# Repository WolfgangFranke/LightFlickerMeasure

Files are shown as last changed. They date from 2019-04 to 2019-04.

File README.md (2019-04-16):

# Light Flicker Measure
## Measures flickering lights, like PWM driven LED-systems, using Arduino.

An old Light Bulb sends 80% constant light and a 20% sine waveform as 100 Hz noise ontop, so no flicker is recognized.

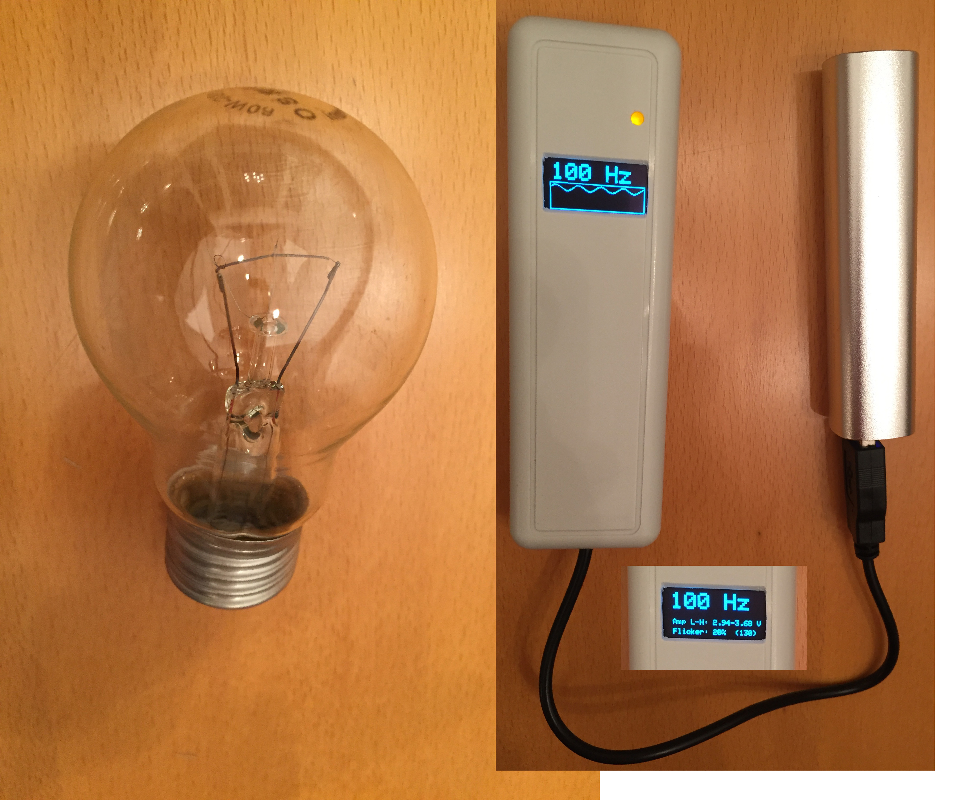
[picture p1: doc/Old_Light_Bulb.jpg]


This LED Streetlamp sends a permanent PWM of 264 Hz frequency instead of a steady light! Going for a walk at night, this lamp is really annoying.

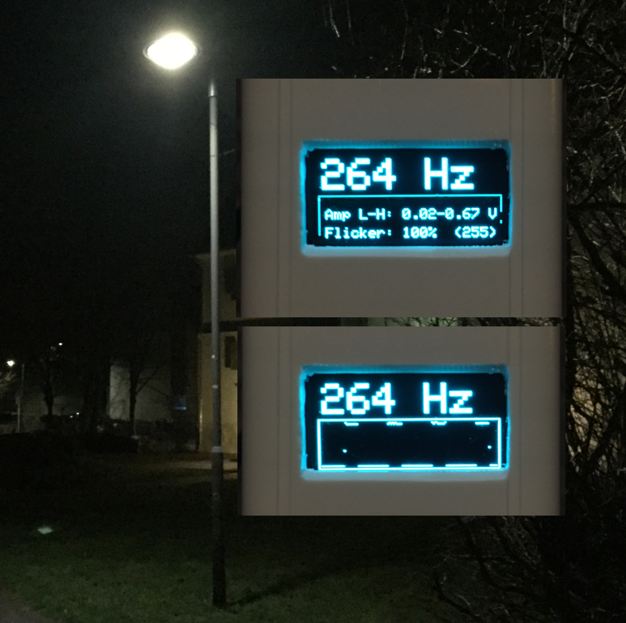
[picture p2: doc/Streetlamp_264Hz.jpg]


Philips Hue Being ceiling light and also the Philips Hue Light Strip+, as well as my Philips Hue RGB light bulbs, run at 1 kHz PWM. That still flickers irritatingly in your eyes when looking around in your appartment. I'm surprised seeing that the Hue Being let's overshoot the light at the begin of a PWM=high, but it may be seen due to the two LEDs providing the CCT.

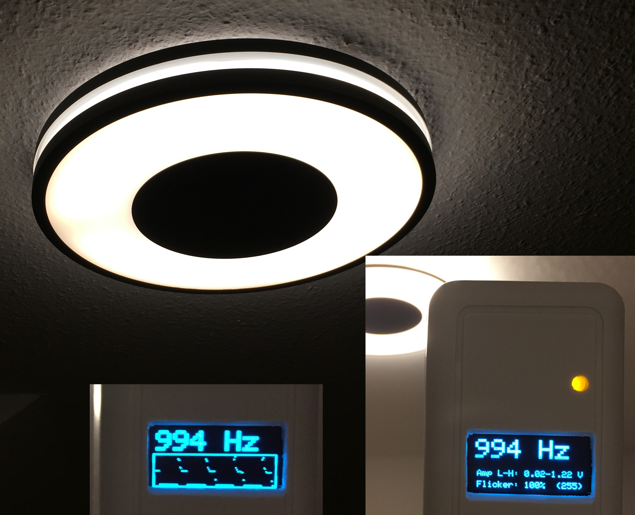
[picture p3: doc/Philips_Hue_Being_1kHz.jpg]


Talking about LED strips, the Paulmann SimpLED-Strip Set (789.56) dims in the PWM frequency range of 2,5 to 4 kHz. Covered by an opaque plastic housing, this could be considered it as less to no flicker. But if you install the strip in direkt sight, a strong flicker will be recognized when moving head or eyes.

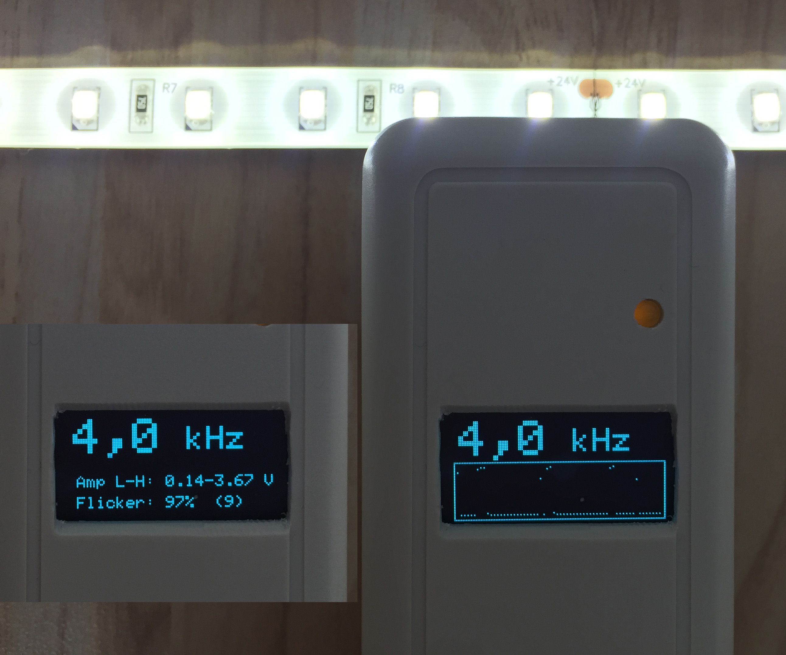
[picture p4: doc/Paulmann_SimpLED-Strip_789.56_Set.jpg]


Totally smooth light sent by a Philips Filament Bulb (not dimmable), I really enjoy it.

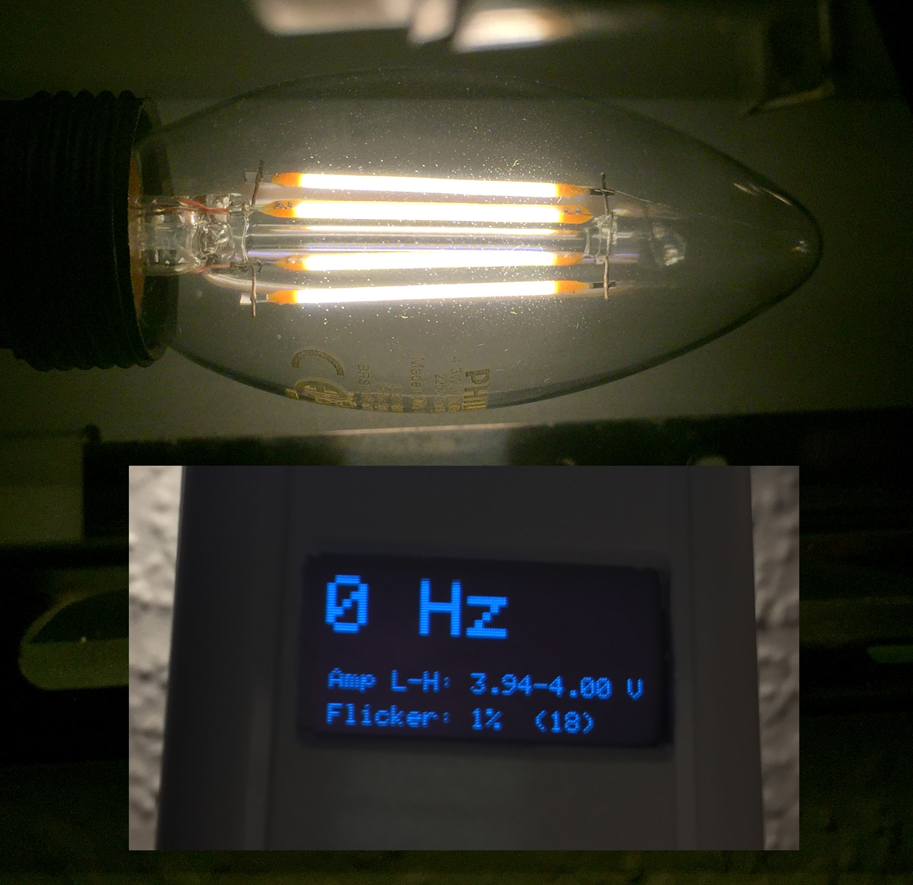
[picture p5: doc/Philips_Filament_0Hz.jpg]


And how about an old-fashioned Neon Lamp, where we all know it does not give a good light? Yep, it does not give a good light!

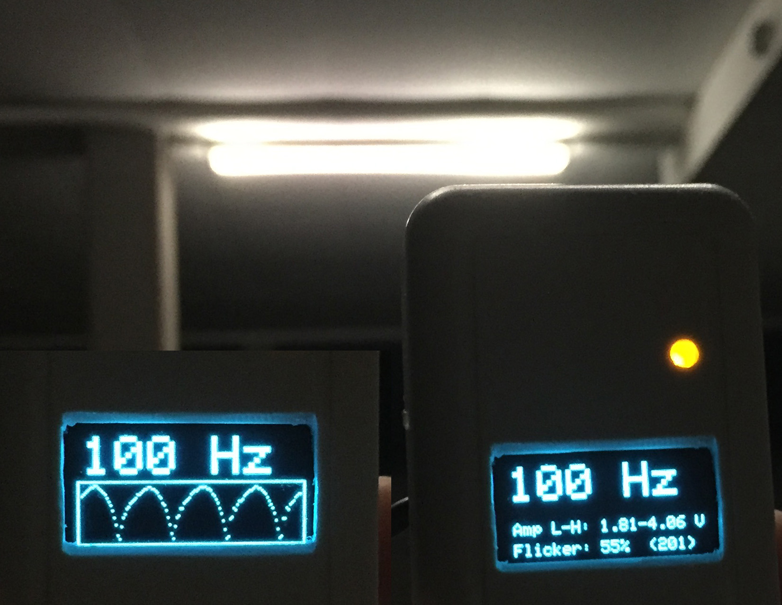
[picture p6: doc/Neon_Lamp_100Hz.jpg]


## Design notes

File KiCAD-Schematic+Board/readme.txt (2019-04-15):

This folder contains the schematic and board layout in KiCAD format.

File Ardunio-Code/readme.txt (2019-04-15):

This folder contains the Arduino scetch.

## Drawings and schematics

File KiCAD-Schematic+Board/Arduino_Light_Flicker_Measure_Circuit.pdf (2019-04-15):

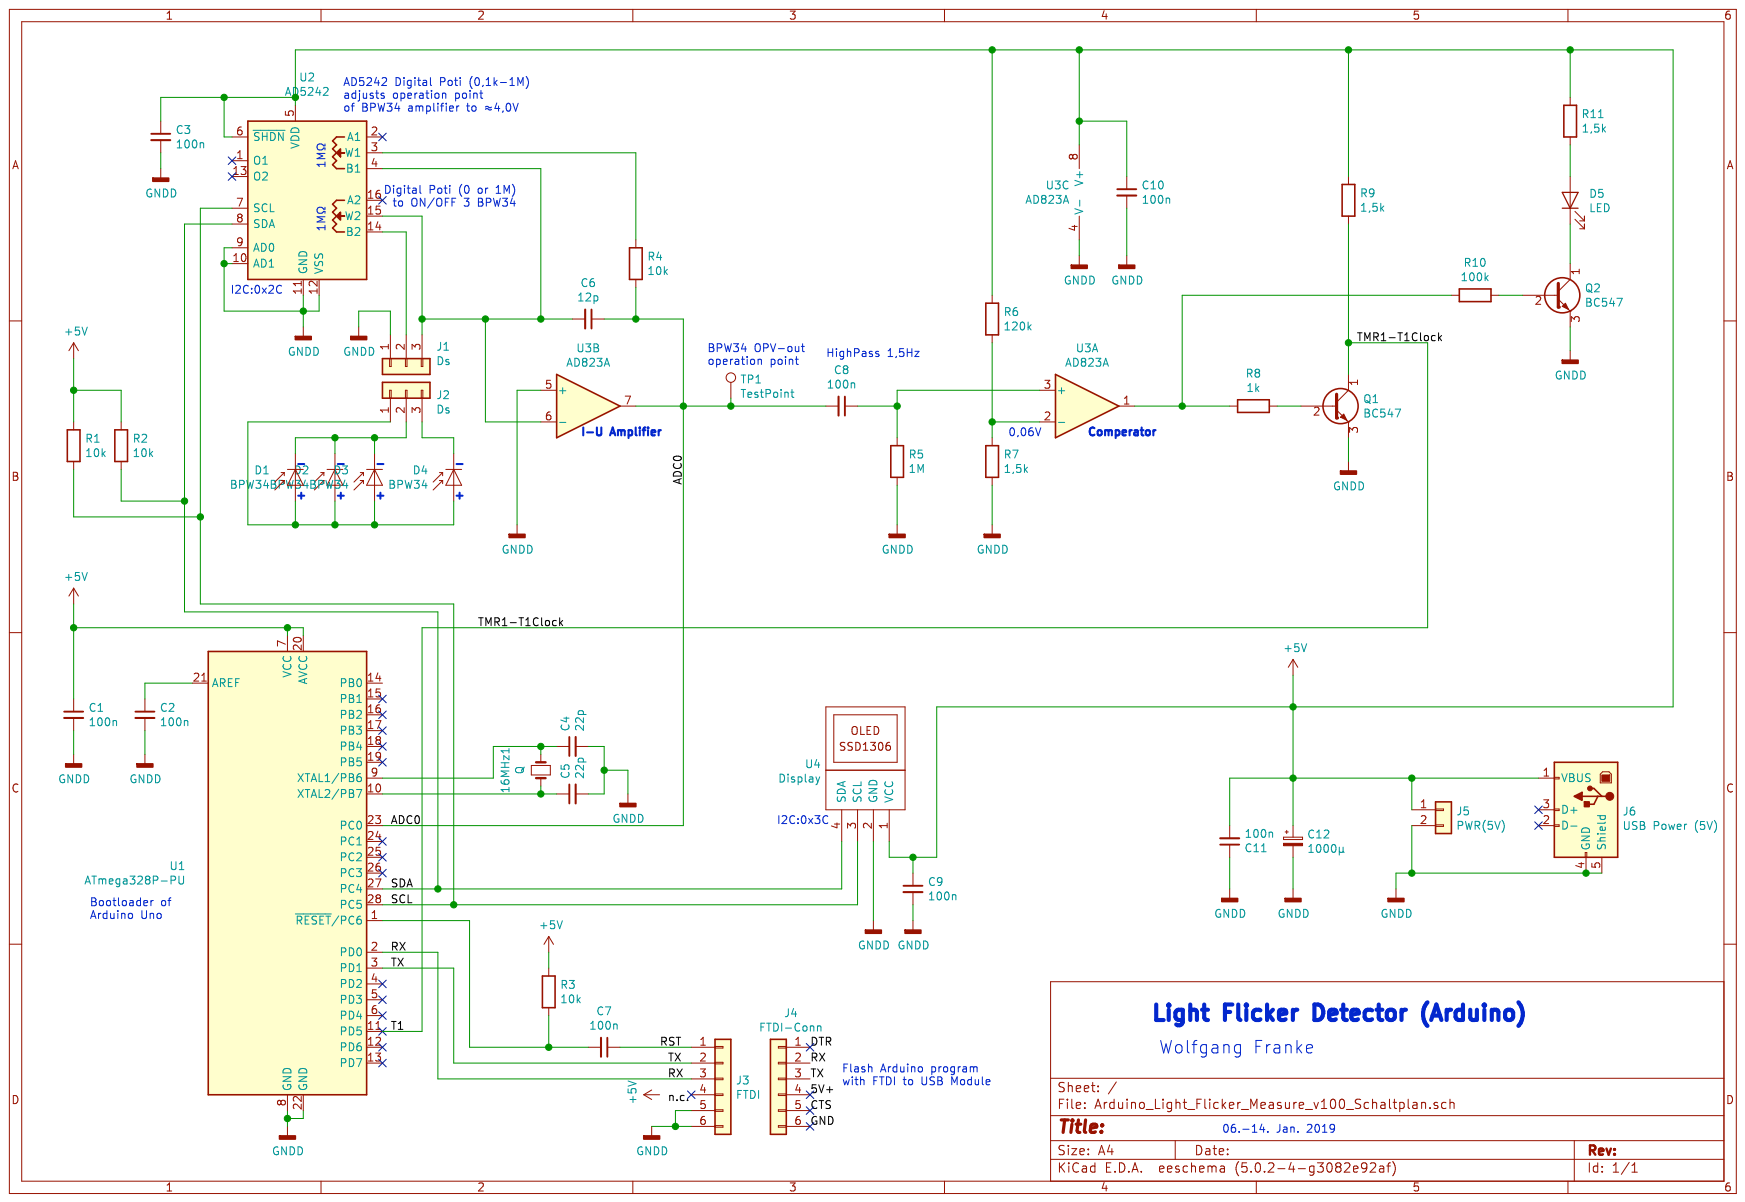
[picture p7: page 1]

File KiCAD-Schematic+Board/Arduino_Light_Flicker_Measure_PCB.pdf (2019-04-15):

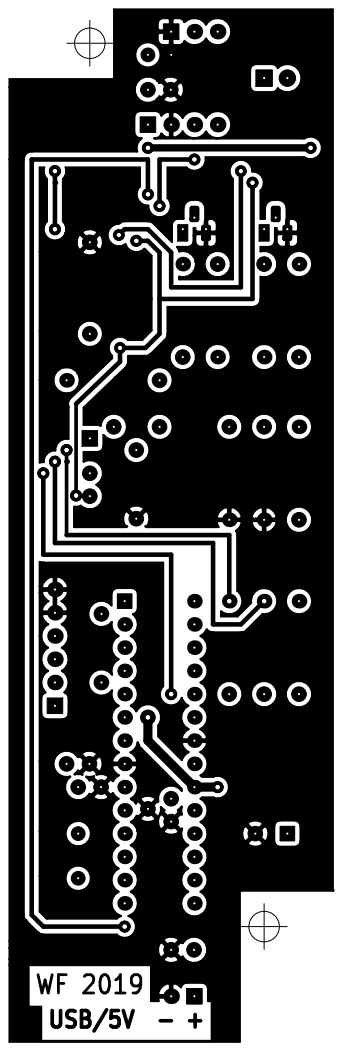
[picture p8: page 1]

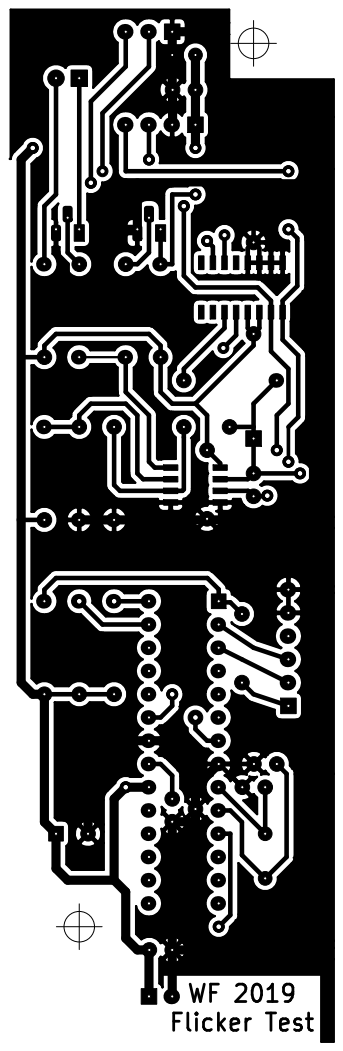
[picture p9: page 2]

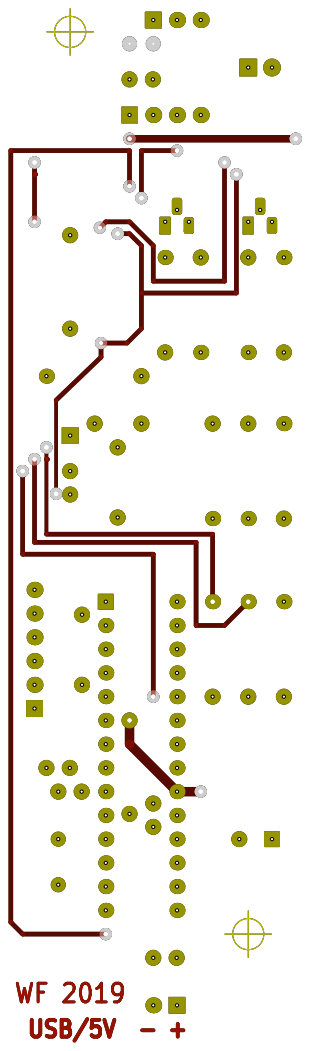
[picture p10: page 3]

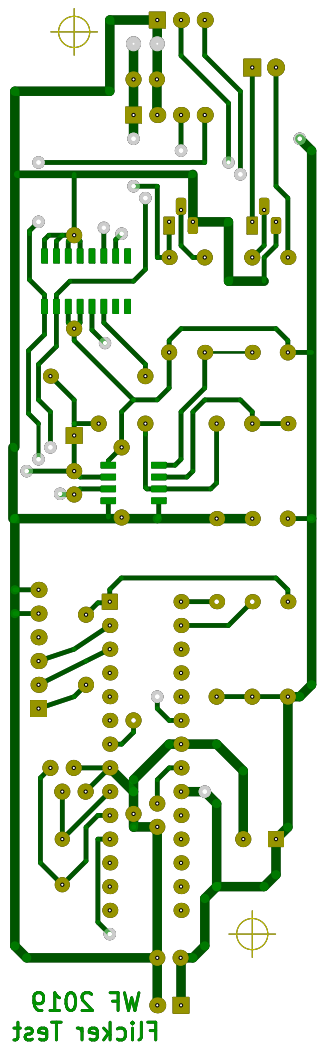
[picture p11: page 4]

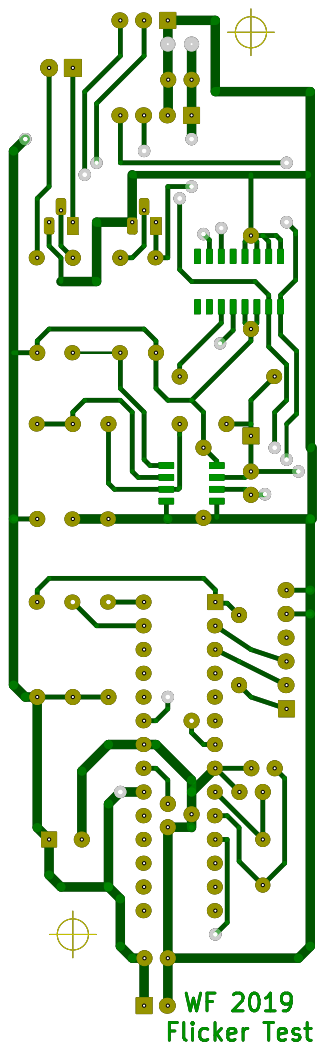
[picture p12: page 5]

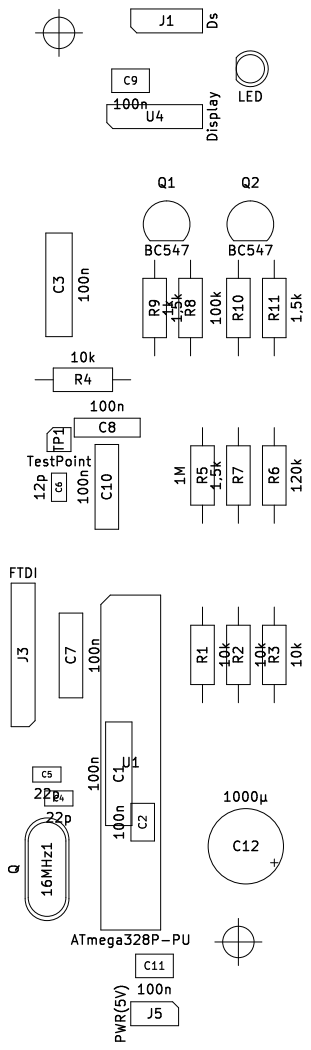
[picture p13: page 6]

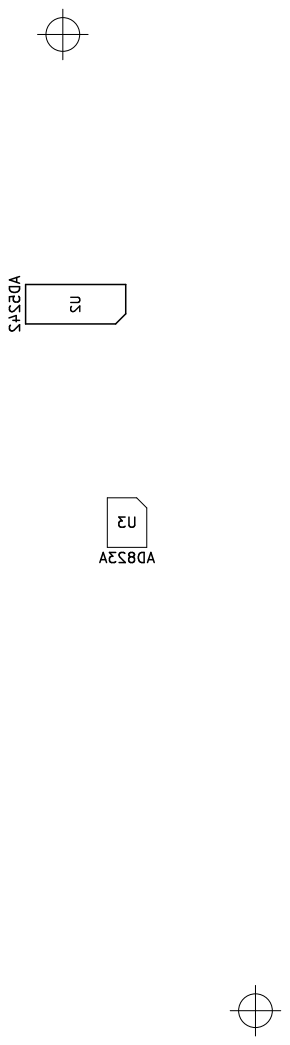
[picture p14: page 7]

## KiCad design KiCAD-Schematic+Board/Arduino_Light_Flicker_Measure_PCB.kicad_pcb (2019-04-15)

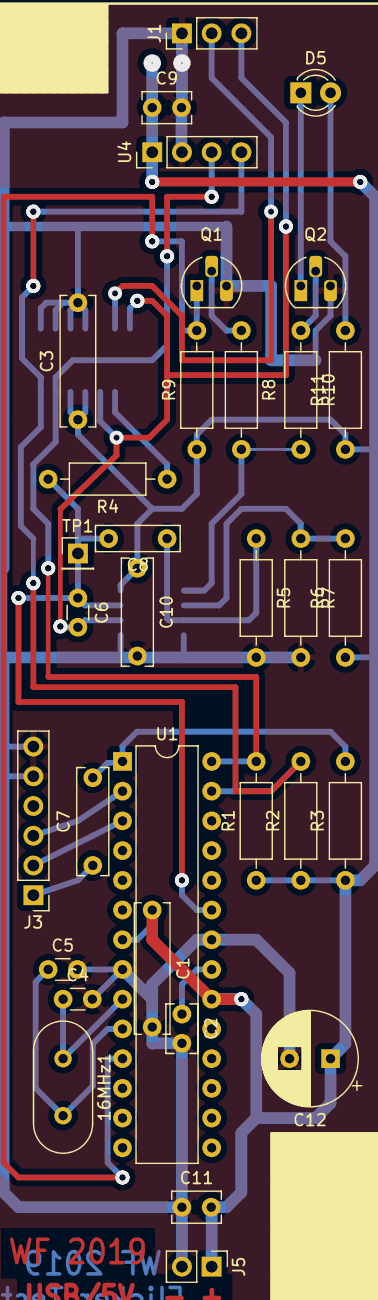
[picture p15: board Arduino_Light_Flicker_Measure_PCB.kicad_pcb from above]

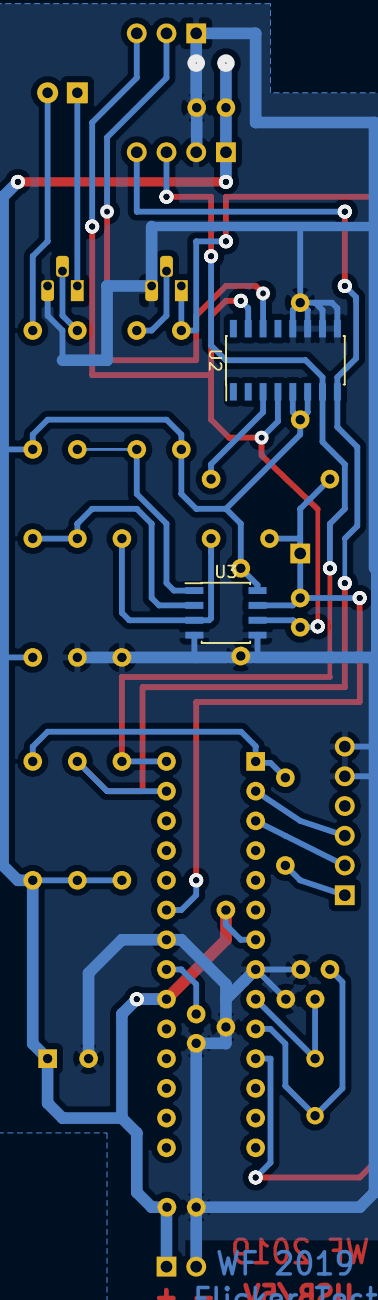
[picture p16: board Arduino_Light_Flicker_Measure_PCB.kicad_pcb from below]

Board: 2 copper layers, 35 parts (2 on the bottom side), 23 nets.

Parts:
16MHz1: Q; Crystal_HC49-U_Vertical
C1, C3: 100n; C_Rect_L11.0mm_W2.8mm_P10.00mm_MKT
C2, C9, C11: 100n; C_Rect_L4.0mm_W2.5mm_P2.50mm
C4, C5: 22p; C_Disc_D3.0mm_W1.6mm_P2.50mm
C6: 12p; C_Disc_D3.0mm_W1.6mm_P2.50mm
C7, C10: 100n; C_Rect_L9.0mm_W2.5mm_P7.50mm_MKT
C8: 100n; C_Rect_L7.0mm_W2.0mm_P5.00mm
C12: 1000µ; CP_Radial_D8.0mm_P3.50mm
D5: LED; LED_D3.0mm
J1: Ds; PinHeader_1x03_P2.54mm_Vertical
J3: FTDI; PinHeader_1x06_P2.54mm_Vertical
J5: PWR(5V); PinHeader_1x02_P2.54mm_Vertical
Q1, Q2: BC547; TO-92_HandSolder
R1, R2, R3, R4: 10k; R_Axial_DIN0207_L6.3mm_D2.5mm_P10.16mm_Horizontal
R5: 1M; R_Axial_DIN0207_L6.3mm_D2.5mm_P10.16mm_Horizontal
R6: 120k; R_Axial_DIN0207_L6.3mm_D2.5mm_P10.16mm_Horizontal
R7, R9, R11: 1,5k; R_Axial_DIN0207_L6.3mm_D2.5mm_P10.16mm_Horizontal
R8: 1k; R_Axial_DIN0207_L6.3mm_D2.5mm_P10.16mm_Horizontal
R10: 100k; R_Axial_DIN0207_L6.3mm_D2.5mm_P10.16mm_Horizontal
TP1: TestPoint; PinHeader_1x01_P2.54mm_Vertical
U1: ATmega328P-PU; DIP-28_W7.62mm
U2: AD5242; SOIC-16_3.9x9.9mm_P1.27mm
U3: AD823A; SOIC-8_3.9x4.9mm_P1.27mm
U4: Display; PinHeader_1x04_P2.54mm_Vertical

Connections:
+5V: C1.1, C3.1, C9.1, C10.1, C11.2, C12.1, J5.1, R1.1, R2.1, R3.1, R6.1, R9.1, R11.1, U1.7, U1.20, U2.5, U2.6, U3.8, U4.1
/ADC0: C6.1, C8.2, R4.2, TP1.1, U1.23, U3.7
/RST: C7.1, J3.1
/RX: J3.3, U1.2
/SCL: R1.2, U1.28, U2.7, U4.3
/SDA: R2.2, U1.27, U2.8, U4.4
/TMR1-T1Clock: Q1.1, R9.2, U1.11
/TX: J3.2, U1.3
GNDD: C1.2, C2.2, C3.2, C4.2, C5.2, C9.2, C10.2, C11.1, C12.2, J1.1, J3.5, J3.6, J5.2, Q1.3, Q2.3, R5.2, R7.2, U1.8, U1.22, U2.9, U2.10, U2.11, U2.12, U3.4, U3.5, U4.2
unnamed: 16MHz1.1, C4.1, U1.9
unnamed: 16MHz1.2, C5.1, U1.10
unnamed: C2.1, U1.21
unnamed: C6.2, J1.3, U2.4, U2.15, U3.6
unnamed: C7.2, R3.2, U1.1
unnamed: C8.1, R5.1, U3.3
unnamed: D5.1, Q2.1
unnamed: D5.2, R11.2
unnamed: J1.2, U2.14
unnamed: Q1.2, R8.1
unnamed: Q2.2, R10.1
unnamed: R4.1, U2.3
unnamed: R6.2, R7.1, U3.2
unnamed: R8.2, R10.2, U3.1

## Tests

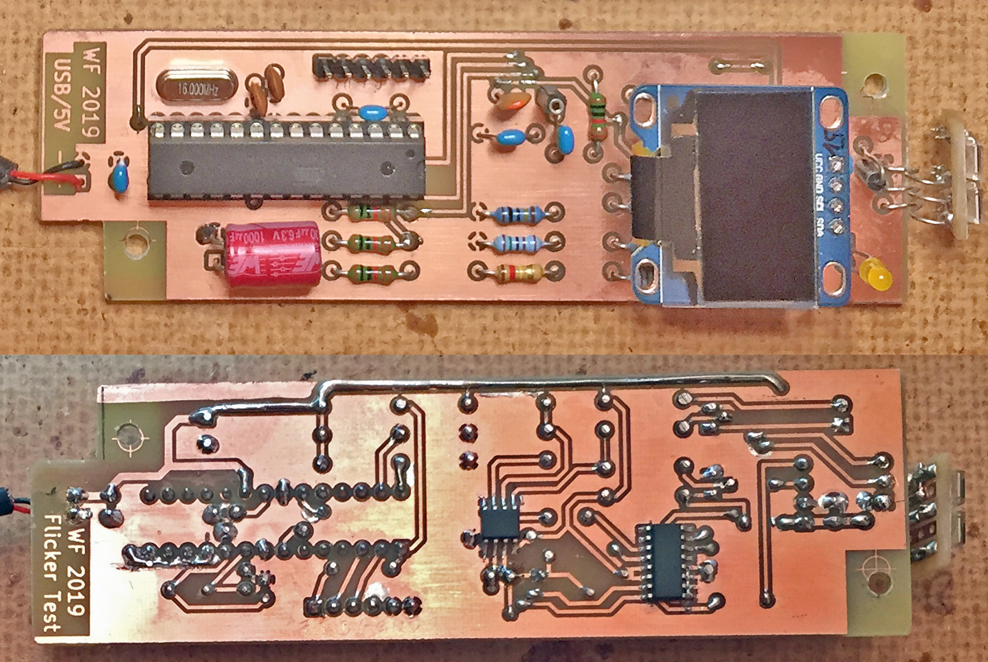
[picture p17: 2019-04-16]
KiCAD-Schematic+Board/Arduino_Light_Flicker_Measure_WF2019.jpg

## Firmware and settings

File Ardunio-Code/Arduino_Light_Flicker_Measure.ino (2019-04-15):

float SW_version = 1.01;
/*
' ######################################################################
' ###
' ###       *** Light Flicker Measure with Arduino (10Hz to 200KHz) ***
' ###       ----------------------------------------------------------
' ###       *Wolfgang Franke*
' ###       Projekt: 02.Jan.2019 - 26.Feb.2019
' ###       Software-Version 1.01    (used IDE: Arduino v1.8.8)
' ###       ----------------------------------------------------------
' ###       Hardware Setup:
' ###       - Analog:   
' ###           + BPW34 Photo Diodes (as fast Light Sensor to receive Light Frequency Pulses)
' ###           + AD823A dual OPV (to I-U convert and amplify light sensor pulses from BPW34) (TLC272 pin-compatible but much faster) 
' ###       - Digital:  
' ###           + ATMega328P with Arduino-Uno Bootloader and FDTI interface (5V, 16 MHz, 32MB Flash)
' ###             + Timer1-Counter clocked by TMR1 T1-externClock/PD5=D5 for counting Light Frequency Pulses
' ###             + ADC0 to measure OPV operation-point voltage (AD823A) and to sample waveform if flicker <10kHz
' ###           + OLED 128x64 (I2C Address: 0x3C)
' ###           + digital Poti AD5242-1M (I2C Address: 0xC2) to control OPV AD823A operation-point and turn ON/OFF 3 of the 4 BPW34 (to allow measure bright light)
' ###
' ###       Function of Light Frequency Measure Loop:
' ###       (1) adjust operating point of OPV (by BPW34 and in amplifier) to match out-signal to Comperator-Input before every Pulse Count of Ardunio CTC
' ###             Pulse high volt target: 4.0V (OPV_PulseHigh_Volt_target) as target operation point, for good signal-to-noise/sunlight ratio
' ###               light is too bright:  Pulse min voltage > 4.4V (OPV_PulseLow_Volt_saturate)
' ###               light is too dark:    Pulse max voltage < 0,1V (OPV_PulseHigh_Volt_weak)
' ###               not used: faint light flicker:  Difference of Pulse max-min voltage < 0,3V (OPV_Pulse_Volt_LH_weak)
' ###       (2) count Pulses (light flicker) on Timer1 T1-externClock-Pin (D5) using Overflow-ISR,  
' ###             1 milli = 1024µs (1000 millis = 1024ms)
' ###             1 sec   = 976,5 millis
' ###             lenght of measure 0,5s has good results for 50Hz
' ###       (3) calculate frequency from Timer1-Counter + Overflow and display on OLED nicely in Hz/kHz,
' ###             1 second counter: INT=65535 is too small for 100kHz
' ###               100Hz = 100/s     => 1s Interval = 100
' ###               1 kHz = 1000/s    => 1s Interval = 1000
' ###              10 kHz = 10.000/s  => 1s Interval = 10.000
' ###             100 kHz = 100.000/s => 1s Interval = 100.000! is>65.535
' ###       (4) measure pulse waveform (for frequency up to 10kHz, with ADC in free-run mode with 76kHz)
' ###       
' ###       known limitations:
' ###         - one analogRead() takes ≈110µs/0,1ms and the 50 loops to determine low/high peak voltage of pulses 
' ###           take ≈5ms and that mathematically works with >200Hz light pulse frequency,
' ###         - if a high or low peak voltage can not be found due to a >5ms light pulse periods (notably <80Hz)
' ###           then if max=0 a wrong flicker=100% and if min=max a wrong flicker=0% will be set,
' ###         - with the Arduino ADC sampling rate of 110µs(9,1kHz) there should be an inability to detect Light Pulses 
' ###           with exactly the same frequency and multiples of it, but this exact condition was non-reproducible,
' ###       
' ######################################################################

/*
' ######################################################################
' ###  Pinbelegungen
' ###  --------------------------------------------------------------
' ###  Arduino      ATMega328P        Flicker Measure
' ###  Uno/ProMini  DIL-28            Beschaltung_WF
' ###  -------------------------------------------------------------
' ###  V-In/RAW     -                 Arduino Power Supply (7V-12V)
' ###  3,3V         -                 Arduino Vout=3,3V (I-out<100mA?)
' ###  5V           -                 Arduino Vout=5V (IN or I-out<200mA)
' ###  
' ###  RESET        (01)                n.c.
' ###  Vcc          (07)              5V+
' ###  Vcc          (20)              5V+
' ###  ARef         (21)                n.c.
' ###  GND          (08)              GND
' ###  GND          (22)              GND
' ###  
' ###  A4/SDA       (27)PC4           I2C-SDA (external Pull-Up 10k to Vcc=5V)
' ###  A5/SCL       (28)PC5           I2C-SCL (external Pull-Up 10k to Vcc=5V)       
' ###  
' ###  D05          (11)PD5           IN TMR1-T1  :  Timer1/Counter1 External Clock Source (T1-externClock Pin)
' ###  A0           (23)A0/PC0        IN ADC0     :  measure Amplifier Operations Point
' ###  D13/SCK      (19)PB5           OUT LED13   :  used for experimantal delay-loop (LED with 330/1K to GND)
' ###  D02/INT0     (04)PD2           IN+Pullup   :  INT0 as frequency pulse counter (not longer used)
' ######################################################################
*/

    
//#########################################################################
//   ******  MCU, Hardware and compiler definitions   ******
//#########################################################################

// *** DEBUG LEVELS ON/OFF ***
#define Serial_waits_for_USB_Enumeration 0    // 0: Serial does NOT wait for USB-Enumeration after Power-ON (Serial-Prints to Terminal get lost until USB-Serial port is re-enumerated)
                                              // 1: Serial-Init waits in loop with timeout of 10 sec for USB-Enumeration after Power-ON (send first Serial.Print sent to Terminal when USB re-enumerated or timeout)
#include <SPI.h>
#include <Wire.h>
#include <Adafruit_GFX.h>
#include <Adafruit_SSD1306.h>

//Definition for ADC
#define ADC_Pin                 0           // Address for ADC free-running mode (is Ardunio A0)
#define ADCPin_OPV_Volt        A0           // analogRead() Address, measure Voltage of OPV operation point for BPW34 amplifier
#define ADC_URef              5.0           // ADC U-Ref in Volt (DEFAUL=5V , INTERNAL 1.1V for ATMega328)

// Declaration for DigiPoti AD5242 connected to I2C (Hardware SDA, SCL pins)
#define AD5242_I2C_Addr     0x2C            // AD5242 I2C address is 0x2C

// Declaration for OLED display with SSD1306 connected to I2C (Hardware SDA, SCL pins)
#define OLED_I2C_Address     0x3C           // Address of OLED (0x3C for China Module, 0x3D for Adafruit compatible)
#define SCREEN_WIDTH          128           // OLED display width, in pixels
#define SCREEN_HEIGHT          64           // OLED display height, in pixels
#define OLED_RESET             -1           // Reset pin # (or -1 if sharing Arduino reset pin)
Adafruit_SSD1306 display(SCREEN_WIDTH, SCREEN_HEIGHT, &Wire, OLED_RESET);

//------------------------------------------------------------------------
//   ******  end MCU, Hardware and compiler definitions   ******
//-------------------------------------------------------------------------


//#########################################################################
//   ****** global variables definitions   ******
//#########################################################################

//define variables for measuring OPV-output voltage on ADC
const float OPV_PulseHigh_Volt_target    = 4.0;      // ca.3.7-4.0V - target operation point for Pulse high voltage, for good signal-to-noise/sunlight ratio
const float OPV_PulseLow_Volt_saturate   = 4.4;      // ca. 4.0-4.5V - higher is too bright (max pulse measured)
const float OPV_PulseHigh_Volt_weak      = 0.1;      // ca. 0.1-0.3V - below is too dark (max pulse measured)

float OPV_Pulse_Volt_max;                       // max Voltage of Pulse for OPV operation point for BPW34 amplifier
float OPV_Pulse_Volt_min;                       // min Voltage of Pulse for OPV operation point for BPW34 amplifier
unsigned int Flicker_Percent;                   // percentage of flicker in light (= (ADC_OPV_Volt_raw_max - ADC_OPV_Volt_raw_min) * 100 / ADC_OPV_Volt_raw_max;)

unsigned int ADC_OPV_Volt_raw;                  // ADC 10 bit value of Voltage of OPV operation point for BPW34 amplifier
unsigned int ADC_OPV_Volt_raw_max;              // stores max ADC 10 bit value of Voltage of OPV operation point for BPW34 amplifier
unsigned int ADC_OPV_Volt_raw_min;              // stores min ADC 10 bit value of Voltage of OPV operation point for BPW34 amplifier

//define variables für Regelkreis zur Einstellung des BPW34-OPV Arbeitspunktes vor jedem Mess-Intervall
unsigned int R_RAW            = 128;            // stores resistor value, starts with POR setting of resistor
const int R_min               = 2;              // min setting of elecronic resistor (0 Ohm)
const int R_max               = 255;            // max setting of elecronic resistor (1M)
boolean R_decreased_flag;                       // request reached (R <= Rmin)
boolean R_increased_flag;                       // request reached (R >= Rmax)

//define variables for counting light frequency pulses on Timer1 T1-externClock
unsigned int Millis_per_Second = 977;           // Arduino: 1 milli = 1024 µs (1 s = 976,56 millis)
unsigned int Measure_Interval_SplitSecond = 2;  // Measure Pulses for real 0,25s or 0,5s
unsigned int Millis_to_Measure;                 // calulated Millis of mesure interval
unsigned long MilliSec_IntervalStart;           // start of voltage measure interval
unsigned long Pulses_counted;                   // counts light frequency pulses on Timer1-Counter
unsigned long CTR1_frequency;                   // calculated frequency on Timer1 T1-externClock
byte CTR1_frequfract;                           // fraction of calculated frequency in KHz
int CTR1_frequency_displayed;                   // stores the decimal value of shortened value in display
byte HzKHz_flag;                                // flag to print Hz or KHz to the display
unsigned long CTR1_frequency_displayed_lastCycle; // saves frequency calculated from last cycle
byte same_frequency_displayed_counter;          // counter of consecutive cycles with same measure, to later display Pulse waveform

//Timer1-Counter
unsigned int overflowCount;                     
unsigned long overflowCopy;
unsigned int timer1CounterValue;

//ADC Pulse waveform probing and printing
unsigned int ADC_save_Interval;                 // interval of ADC measure for Pulse waveform probing
byte ADCvalues[128];                            // stores ADC values of pulse waveform measures
byte ADCvalue_Pointer;                          // pointer to array ADCvalues[]
byte ADCSRA_save;                               // saves the Register while ADC free-running mode
byte ADCSRB_save;                               // saves the Register while ADC free-running mode
byte ADMUX_save;                                // saves the Register while ADC free-running mode
unsigned int max_yValue;                        // max value of all waveform samples to display
unsigned int scaled_yValue;                     // waveform samples value scaled to display pixels

//-------------------------------------------------------------------------
//   ****** End of global variables definitions ******
//-------------------------------------------------------------------------



//#########################################################################
//    ****** main program init ******
//#########################################################################

// main setup
void setup() 
{
//- - - - - - - - - - - - - - - - - - - - - - - - - - - - - - - - - - - - -
  // *** MCU config ***
  
  // pin for INT0
//  pinMode(2, INPUT_PULLUP);     // INT0: init as input (Arduino Digital-2 = ATMega328 PD2/INT0)
  pinMode(13, OUTPUT);            // used for the "experimental" Delay-Loop (3,5µs) when sampling ADC of pulse


  //Initialize serial port 
  Serial.begin(115200);
  if (Serial_waits_for_USB_Enumeration == 0)                  // wait for serial port if flag Serial_waits_for_USB_Enumeration is set
  {
    unsigned long MillisWait = millis() + 10000;              // timeout 10s if serial connection to PC established
    while (!Serial)                                           // wait for serial port to open (restart Terminal program)
    {  
      if (millis() > MillisWait)                              // timeout?
      {
        break;                                                // timeout, start program without Serial Communication
      }      
    }  
  } //end init serial port
  Serial.println(F("Welcome @ Arduino (115200 baud)"));        
  Serial.print(F("Light Flicker Measure - W.Franke 2019 - v"));    
  Serial.println(SW_version, 2);                               
  Serial.println(F(" "));
  
  //config ADC
  analogReference(DEFAULT);           // URef = Vcc=5V   // analogReference(INTERNAL); // URef=1,1V

//- - - - - - - - - - - - - - - - - - - - - - - - - - - - - - - - - - - - -
  // *** external hardware config ***
  
  //config OLED Display and used Font
  if(!display.begin(SSD1306_SWITCHCAPVCC, OLED_I2C_Address))      // SSD1306_SWITCHCAPVCC = generate display voltage from 3.3V internally
  { 
    Serial.println(F("SSD1306 allocation failed"));
  }
  display.setFont();                  // set default font with size (setCursor(x,y) points to lower-left pixel of first character)
  display.setTextColor(WHITE);        // set text "white" (FYI: (BLACK, WHITE) = inverse text)
  display.setTextSize(1);             // set 1x scale text (scales bitmat, that's not a vector font)

  //init DigiPoti at 50%
  Set_DigiPoti_newValue_for_OPV(R_RAW);       // init DigiPoti R1 in feedback loop of OPV to 500k 
    
  splashscreen();                     // Show splash screen
  delay(3000); 
  display.clearDisplay();  

//- - - - - - - - - - - - - - - - - - - - - - - - - - - - - - - - - - - - -
  // *** Software config ***
  same_frequency_displayed_counter = 1;      // reset counter of consecutive cycles with same measure, to later display Pulse waveform
  CTR1_frequency_displayed_lastCycle = 0;    // reset frequency calculated from last cycle

}//end of Arduino "Setup"
//-------------------------------------------------------------------------
//   ****** End setup ******
//-------------------------------------------------------------------------




//#########################################################################
//    ****** Arduino main program loop ******
//#########################################################################

//Arduino main loop
void loop() 
{

//- - - - - - - - - - - - - - - - - - - - - - - - - - - - - - - - - - - - - - - - - - - -
// *** (1A) read current Pulse Voltage of OPV operation point for BPW34 amplifier on output ***
//- - - - - - - - - - - - - - - - - - - - - - - - - - - - - - - - - - - - - - - - - - - -

  Set_DigiPoti_newValue_for_BPW34(0);         // init DigiPoti R2 to turn ON all BPW34 diodes for normal/low brightness
 
  // measure pulse low and high peak voltage    
  // one analogRead() takes ≈110µs/0,1ms => 50 loops take ≈5ms and that duration mathematically will catch the low/high change of a pulse >200Hz
  // tests have shown good statistical zero crossing detection down to 100Hz (10ms pulse width)
  // but below 50Hz (>20ms pulse width) nearly no zero crossing is detected, and low/high peak will become same resulting (risk of "division by zero" for flicker-percent)
  ADC_OPV_Volt_raw_min = 1024;
  ADC_OPV_Volt_raw_max = 0;                               // reset ADC_OPV_Volt_raw_max
  for (byte i=0; i <= 50; i++)                            // try to find the peak of "alternating" voltage by statistically probing the wafeform
  {
    ADC_OPV_Volt_raw = analogRead(ADCPin_OPV_Volt);       // read ADC 10-bit raw value
    if (ADC_OPV_Volt_raw > ADC_OPV_Volt_raw_max)          // store max volt of BPW34 amplifier on output
    {
      ADC_OPV_Volt_raw_max = ADC_OPV_Volt_raw;
    }
    if (ADC_OPV_Volt_raw < ADC_OPV_Volt_raw_min)          // store min volt of BPW34 amplifier on output
    {
      ADC_OPV_Volt_raw_min = ADC_OPV_Volt_raw;
    } 
  } 
  OPV_Pulse_Volt_min = ADC_OPV_Volt_raw_min * ADC_URef / 1023 ; // map ADC raw (int) to volt (float)
  OPV_Pulse_Volt_max = ADC_OPV_Volt_raw_max * ADC_URef / 1023 ; // map ADC raw (int) to volt (float)
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
